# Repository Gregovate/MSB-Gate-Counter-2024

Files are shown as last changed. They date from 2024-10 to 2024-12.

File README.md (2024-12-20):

# Gate Counter Project

## Overview
The Gate Counter project is designed to monitor vehicle traffic exiting a park using sensors and microcontroller technology. It uses an ESP32 microcontroller to:

- Detect vehicles using a magnetic sensor and beam sensor.
- Log and publish vehicle counts via MQTT.
- Save data to an SD card for persistence and analysis.
- Provide real-time statistics via an OLED display.
- Enable remote monitoring and updates using WiFi and Over-The-Air (OTA) updates.

This system is an essential tool for traffic control and capacity management in parks or similar facilities.

## Features

### Sensors and Detection
- **Magnetic Sensor**: Detects metallic objects.
- **Beam Sensor**: Confirms vehicle presence.
- **Car Detection Logic**: Uses a state machine for accurate detection.

### Data Management
- Saves hourly, daily, and show-specific vehicle counts to an SD card.
- Provides recovery and persistence across reboots.
- Publishes data via MQTT to a remote server.

### Networking
- Supports multiple WiFi networks using WiFiMulti.
- Publishes car counts, temperature, humidity, and other metrics via MQTT.
- Includes a web server for file operations and remote interactions.

### Real-Time Display
- OLED display provides live updates on vehicle counts, temperature, and other metrics.

### Environmental Monitoring
- Logs temperature and humidity data using a DHT22 sensor.

### Timekeeping
- Synchronizes time using an RTC and NTP server.
- Automates actions such as resetting counts and saving summaries at specific times.

### OTA Updates
- ElegantOTA integration allows for seamless firmware updates.

---

## Documentation

For more detailed information about specific components, see the following:

- [MQTT Reset Topics](docs/mqtt_reset_topics.md): Detailed descriptions of MQTT reset topics and their payloads.
- [Changelog](docs/changelog.md): A history of updates, fixes, and new features in the Gate Counter project.

---

## Setup Instructions
1. **Hardware Requirements**:
   - ESP32 microcontroller (DOIT DevKit V1 recommended).
   - DHT22 sensor for temperature and humidity.
   - Magnetic and beam sensors for vehicle detection.
   - OLED display (128x64 resolution).
   - SD card and reader module.

2. **Software Requirements**:
   - Arduino IDE with necessary libraries:
     - `ArduinoJson`
     - `PubSubClient`
     - `Adafruit_GFX` and `Adafruit_SSD1306`
     - `RTClib`, `NTPClient`
     - `DHT` and `DHT_U`

3. **Connections**:
   - Connect sensors, SD card, and OLED display to the ESP32 as specified in the code comments.

4. **Configuration**:
   - Edit `secrets.h` to include WiFi credentials.
   - Adjust MQTT topics and server settings as needed.

5. **Deployment**:
   - Upload the firmware using Arduino IDE.
   - Monitor system logs via Serial Monitor for debugging.

---

## Future Enhancements
- Integrate a web-based dashboard for real-time monitoring.
- Add support for additional sensors and analytics.
- Improve power efficiency for extended deployments.

---

For further assistance or to contribute to the project, please contact the developer:
**Greg Liebig**  
Email: `gliebig@sheboyganlights.org`

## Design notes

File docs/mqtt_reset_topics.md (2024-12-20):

# MQTT Reset Topics - Gate Counter

This document provides descriptions for the MQTT reset topics supported by the Gate Counter system. These topics allow remote control and configuration of various counters and states within the system.

---

## Subscribed Topics for Resets

### 1. `msb/traffic/GateCounter/resetDailyCount`
- **Description**: Resets the total daily vehicle count to a specified value.
- **Payload**: Integer representing the new value for the daily counter.
- **Example**:
  - Payload: `0` (Resets the daily vehicle count to 0.)

---

### 2. `msb/traffic/GateCounter/resetShowCount`
- **Description**: Resets the total show vehicle count.
- **Payload**: Integer representing the new value for the show counter.
- **Example**:
  - Payload: `50` (Sets the show vehicle count to 50.)

---

### 3. `msb/traffic/GateCounter/resetDayOfMonth`
- **Description**: Manually resets the calendar day to a specific value.
- **Payload**: Integer representing the new day of the month.
- **Example**:
  - Payload: `15` (Sets the day of the month to the 15th.)

---

### 4. `msb/traffic/GateCounter/resetDaysRunning`
- **Description**: Resets the total number of days the show has been running.
- **Payload**: Integer representing the new value for days running.
- **Example**:
  - Payload: `10` (Resets the "days running" counter to 10.)

---

### 5. `msb/traffic/GateCounter/gateCounterTimeout`
- **Description**: Updates the timeout duration for the gate counter.
- **Payload**: Integer in milliseconds specifying the new timeout.
- **Example**:
  - Payload: `60000` (Sets the timeout duration to 60 seconds.)

---

### 6. `msb/traffic/GateCounter/carDetectMS`
- **Description**: Updates the minimum wait duration for confirming a vehicle.
- **Payload**: Integer in milliseconds specifying the new detection duration.
- **Example**:
  - Payload: `1500` (Sets the detection duration to 1.5 seconds.)

---

### 7. `msb/traffic/GateCounter/loggingEnabled`
- **Description**: Toggles the logging of sensor data.
- **Payload**:
  - `1`: Enables logging.
  - `0`: Disables logging.
- **Example**:
  - Payload: `1` (Enables logging of sensor data.)

---

## Notes
- Ensure all payloads are sent as valid integers where applicable.
- Use these topics to remotely manage the Gate Counter system for improved flexibility and responsiveness.

---

For further assistance, contact the system administrator or refer to the Gate Counter documentation.

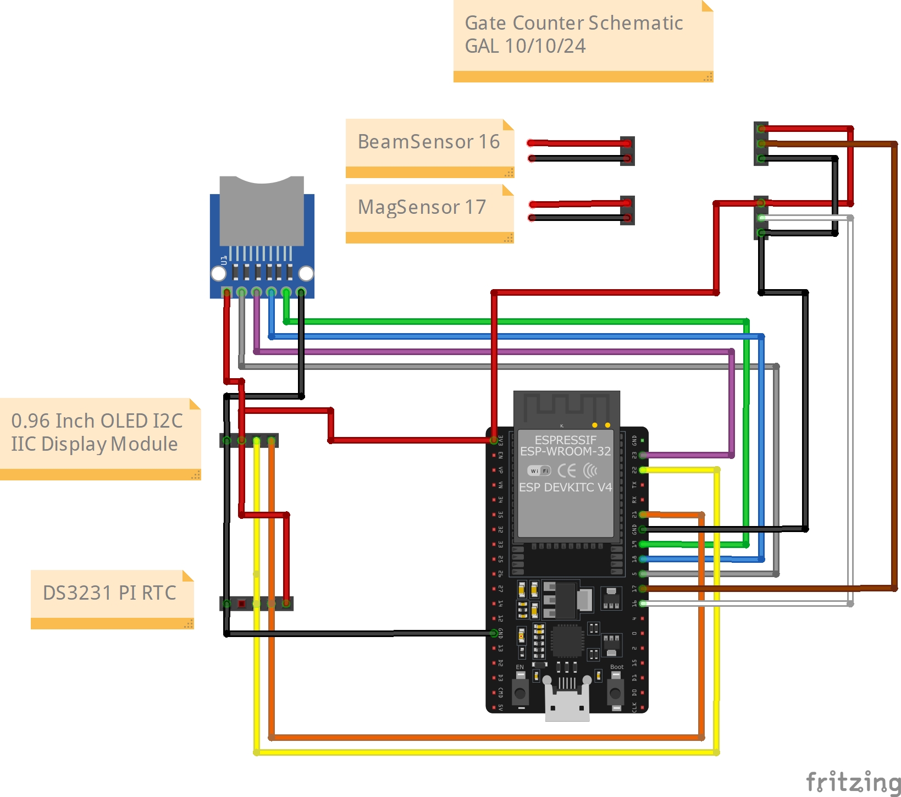
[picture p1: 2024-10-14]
docs/Gate Counter_bb.jpg

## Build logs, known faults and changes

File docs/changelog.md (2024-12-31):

### [24.12.26.1] - YYYY-MM-DD
- Added alarm if beam sensor remains high for more than 3 minutes

### [24.12.19.6] - YYYY-MM-DD
- Removed temperature array from average procedure an used the global declared array

### [24.12.19.5] - YYYY-MM-DD
- Accidentally removed mqtt_client.setCallback(callback) Fixed with a forward declaration

### [24.12.19.4] - YYYY-MM-DD
- Added save saveHourlyCounts() to countTheCar() and removed save from OTA update

### [24.12.18.4] - YYYY-MM-DD
- added  pinMode(DHTPIN, INPUT_PULLUP) for DHT Sensor getting bad readings.  77.1% (used 1010645 bytes from 1310720 bytes)

### [24.12.18.2] - YYYY-MM-DD
- put publishing state changes beamSensorState and magSensorState and timeToPassMS. detectCar() finally working reliably!

### [24.12.18.1] - YYYY-MM-DD
- Renamed hourlyCarCount[] to hourlyCount[] and finished comparison to Car Counter Code

### [24.12.17.4] - YYYY-MM-DD
- added new topic MQTT_COUNTER_LOG "msb/traffic/GateCounter/CounterLog"

### [24.12.17.3] - YYYY-MM-DD
- more tweaks to detectCar() revised averageHourlyTemp() & readTempandRH() removed averageHourlyTemp() from Loop

### [24.12.17.2] - YYYY-MM-DD
- modified detectCar() based on logging data increased predetect mag sensor to 750ms

### [24.12.17.1] - YYYY-MM-DD
- modified downloadSDFile(AsyncWebServerRequest *request) to save file with correct filename

### [24.12.16.4] - YYYY-MM-DD
- Reset counts was incorrect due to syncing code from car counter to gate counter should be 5:10 pm for gate counter

### [24.12.16.3] - YYYY-MM-DD
- was not incrementing hourly car counts and writing multiple rows for the same date

### [24.12.16.2] - YYYY-MM-DD
- removed all references to tempF from RTC sensor moved to DHT22 sensor publish every 10 min publish temp & RH json format

### [24.12.16.1] - YYYY-MM-DD
- revised saveDailyShowSummary() times to 9:20 for gate counter

### [24.12.15.4] - YYYY-MM-DD
- revised saveDailyShowSummary() to average temps during show

### [24.12.15.3] - YYYY-MM-DD
- after debugging in field after 15.2

### [24.12.15.2] - YYYY-MM-DD
- Matched Car Counter procedures, Changed Names, Added webserver

### [24.12.14.2] - YYYY-MM-DD
- added getdayofmonth() after updatingdayofmonth()

### [24.12.14.1] - YYYY-MM-DD
- Added DHT22 sensor to gate counter. Revised carDetect to weight beamSensor higher and used magSensor for additional Confirmation

### [24.12.12.3] - YYYY-MM-DD
- Tweaks to state machine for improving accuracy. Added timers for analysis topics 16 & 18

### [24.12.12.2] - YYYY-MM-DD
- Revising detectCars() State machine logic for new sensor

### [24.12.12.1] - YYYY-MM-DD
- BREAKING CHANGE Replaced reflective sensor with through beam nomally closed invert reading

### [24.12.02.3] - YYYY-MM-DD
- added timer for timeDiff between magSensor HIGH and beamSensor HIGH and timer between cars

### [24.12.02.1] - YYYY-MM-DD
- revised state machine again for through-beam sensor and removed bounce detection for beam

### [24.12.01.3] - YYYY-MM-DD
- revised state machine again for beam sensor bouncing during car detection

### [24.12.01.2] - YYYY-MM-DD
- revised state machine for beam sensor bouncing

### [24.12.01.1] - YYYY-MM-DD
- converted car dection to state machine in separate branch

### [24.11.30.3] - YYYY-MM-DD
- Totally Reworked Car Detection

### [24.11.30.2] - YYYY-MM-DD
- Refactored publishMQTT and File Checking and Creation and for loop hour counts

### [24.11.30.1] - YYYY-MM-DD
- Updated MQTT callback section to clean up potential memory leak

### [24.11.27.1] - YYYY-MM-DD
- Changed mqtt publish outside File writes, changed daily totals to string pointer, tempF to float

### [24.11.26.1] - YYYY-MM-DD
- Changed Update to days running since they were doubling on date change

### [24.11.25.2] - YYYY-MM-DD
- Added in state change in loop to publish mag sensor states. Missed 5 cars during dog show.

### [24.11.25.1] - YYYY-MM-DD
- Added MQTT Topics for Remote Reset to match Car Counter. Added Alarm for blocked beam sensor

### [24.11.19.1] - YYYY-MM-DD
- Replace Current Day & Calday with DayOfMonth. Added boolean to print daily summary once

### [24.11.18.1] - YYYY-MM-DD
- Added publishing totals on manual reset

### [24.11.15.1] - YYYY-MM-DD
- Removed Sensor Bounces, updated MQTT Topics

### [24.11.14.1] - YYYY-MM-DD
- Eliminated mqtt timeout, debug topic, added TTP to mqtt

### [24.11.10.2] - YYYY-MM-DD
- Miscellaneous formatting issues before re-creating JSON branch again

### [24.11.10.1] - YYYY-MM-DD
- Fixed bounce check, changed filename methods merged Arduino json branch

### [24.10.28.1] - YYYY-MM-DD
- Created proceedure for Updating Car Counts

### [24.10.27.1] - YYYY-MM-DD
- simplified car detect logic, Formatting Changes

### [24.10.23.3] - YYYY-MM-DD
- Fixed File creation errors

### [24.10.23.2] - YYYY-MM-DD
- Added update/reset check in loop for date changes. Created initSDCard().

### [24.10.23.1] - YYYY-MM-DD
- Updated totals, bug fixes, files ops comparrison to Gate counter  added file ops

### [24.10.17.2] - YYYY-MM-DD
- added #define FWVersion

### [24.10.15.0] - YYYY-MM-DD
- Fixed Pin problem. Beam & mag sensor swapped causing the problems. Purpose: suppliments Car Counter to improve traffic control and determine park capacity

### [23.12.13.0] - YYYY-MM-DD
- Changed time format YYYY-MM-DD hh:mm:ss 12/13/23

# Changelog

## Version History

### Version 24.12.19.3
- Synced shared code between Gate Counter and Car Counter.
- Resolved warnings and removed unused variables.
- Updated `carDetectMS` default value to 1200ms.
- Enhanced SD card file operations for better persistence.
- Fixed remaining issues with HTML file handling.

### Version 24.12.19.2
- Addressed warnings during compilation.
- Improved handling of unused variables.
- Simplified configuration settings.

### Version 24.12.19.1
- Added functionality to save hourly data before firmware updates.
- Set hostname dynamically for multiple instances.
- Improved MQTT topic structure for consistency.
- Enhanced firmware update compatibility by modifying `secrets.h`.

### Version 24.12.18.6
- Introduced `flagHourlyReset` for better hourly data saving.
- Enhanced logging capabilities for analysis and debugging.

### Version 24.12.18.5
- Added dynamic MQTT topics for hourly car totals.
- Enhanced reliability of `detectCar()` functionality.

### Version 24.12.18.3
- Added new statistics for "Time Between Cars" and beam sensor high time.
- Refined state machine logic for car detection.

### Version 24.12.16.5
- Introduced logging functions for sensor data analysis.
- Updated daily reset logic for improved consistency.

### Version 24.11.25.3
- Improved MQTT topic management.
- Resolved car detection discrepancies during specific scenarios.

### Version 24.10.24.1
- Addressed errors in MQTT variable declarations.
- Refined daily total management for better accuracy.

---

## Notes
- For further details, refer to the documentation or contact the system administrator.
- Future releases will focus on enhancing real-time analytics and integrating additional sensor support.

---

For more information, see the [README.md](README.md) file.

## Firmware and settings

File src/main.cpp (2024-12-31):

/*
Gate Counter by Greg Liebig greg@engrinnovations.com
Initial Build 12/5/2023 12:15 pm
Counts vehicles as they exit the park
Connects to WiFi and updates RTC on Boot
Uses an Optocoupler to read burried vehicle sensor for Ghost Controls Gate operating at 12V
Purpose: suppliments Car Counter to improve traffic control and determine park capacity
Uses an Optocoupler to read burried vehicle sensor for Ghost Controls Gate operating at 12V
DOIT DevKit V1 ESP32 with built-in WiFi & Bluetooth
*/

/*
## BEGIN CHANGELOG ##
24.12.26.1 Added alarm if beam sensor remains high for more than 3 minutes
24.12.19.6 Removed temperature array from average procedure an used the global declared array
24.12.19.5 Accidentally removed mqtt_client.setCallback(callback) Fixed with a forward declaration
24.12.19.4 Added save saveHourlyCounts() to countTheCar() and removed save from OTA update
24.12.19.3 File comparrison between Car Counter and Gate Counter. Synced shared code
24.12.19.2 fixed warnings, removed unused variables, Changed waitduration to carDetectMS Only errors are with html. Changed carDetectMS default 1200
24.12.19.1 Included saving hourly data before uploading new firmware, Set hostname, MultiMQTT, modified secrets.h
24.12.18.6 Changed flags to save certain data hourly flagHourlyReset
24.12.18.5 Fixed MQTT dymanic topic in CountTheCar for hourly totals 
24.12.18.4 added  pinMode(DHTPIN, INPUT_PULLUP) for DHT Sensor getting bad readings.  77.1% (used 1010645 bytes from 1310720 bytes)
24.12.18.3 Added new stat Time Between Cars. Put back BeamSensor High Time
24.12.18.2 put publishing state changes beamSensorState and magSensorState and timeToPassMS. detectCar() finally working reliably!
24.12.18.1 Renamed hourlyCarCount[] to hourlyCount[] and finished comparison to Car Counter Code
24.12.17.4 added new topic MQTT_COUNTER_LOG "msb/traffic/GateCounter/CounterLog"
24.12.17.3 more tweaks to detectCar() revised averageHourlyTemp() & readTempandRH() removed averageHourlyTemp() from Loop
24.12.17.2 modified detectCar() based on logging data increased predetect mag sensor to 750ms
24.12.17.1 modified downloadSDFile(AsyncWebServerRequest *request) to save file with correct filename
24.12.16.5 Added logging function to plot sensor data. Changes getHourlyData() & saveHoulyCounts()
24.12.16.4 Reset counts was incorrect due to syncing code from car counter to gate counter should be 5:10 pm for gate counter
24.12.16.3 was not incrementing hourly car counts and writing multiple rows for the same date
24.12.16.2 removed all references to tempF from RTC sensor moved to DHT22 sensor publish every 10 min publish temp & RH json format
24.12.16.1 revised saveDailyShowSummary() times to 9:20 for gate counter
24.12.15.4 revised saveDailyShowSummary() to average temps during show
24.12.15.3 after debugging in field after 15.2
24.12.15.2 Matched Car Counter procedures, Changed Names, Added webserver
24.12.14.2 added getdayofmonth() after updatingdayofmonth()
24.12.14.1 Added DHT22 sensor to gate counter. Revised carDetect to weight beamSensor higher and used magSensor for additional Confirmation
24.12.12.3 Tweaks to state machine for improving accuracy. Added timers for analysis topics 16 & 18
24.12.12.2 Revising detectCars() State machine logic for new sensor
24.12.12.1 BREAKING CHANGE Replaced reflective sensor with through beam nomally closed invert reading
24.12.02.3 added timer for timeDiff between magSensor HIGH and beamSensor HIGH and timer between cars
24.12.02.1 revised state machine again for through-beam sensor and removed bounce detection for beam
24.12.01.3 revised state machine again for beam sensor bouncing during car detection
24.12.01.2 revised state machine for beam sensor bouncing
24.12.01.1 converted car dection to state machine in separate branch
24.11.30.3 Totally Reworked Car Detection
24.11.30.2 Refactored publishMQTT and File Checking and Creation and for loop hour counts
24.11.30.1 Updated MQTT callback section to clean up potential memory leak
24.11.27.1 Changed mqtt publish outside File writes, changed daily totals to string pointer, tempF to float
24.11.26.1 Changed Update to days running since they were doubling on date change
24.11.25.3 Cleaned up MQTT Topics
24.11.25.2 Added in state change in loop to publish mag sensor states. Missed 5 cars during dog show.
24.11.25.1 Added MQTT Topics for Remote Reset to match Car Counter. Added Alarm for blocked beam sensor
24.11.19.1 Replace Current Day & Calday with DayOfMonth. Added boolean to print daily summary once
24.11.18.1 Added publishing totals on manual reset
24.11.15.1 Removed Sensor Bounces, updated MQTT Topics
24.11.14.1 Eliminated mqtt timeout, debug topic, added TTP to mqtt
24.11.10.2 Miscellaneous formatting issues before re-creating JSON branch again
24.11.10.1 Fixed bounce check, changed filename methods merged Arduino json branch
24.11.9.2 Added mqtt publish when car counter cars updates
24.11.9.1 Added mqtt loop to while loop. Working code excluding elegantota update
24.11.8.1 testing beamSensorBoune time
24.11.6.2 Increased carDetectTime from 500 to 750 millis Sensor bounces with my truck
24.11.6.1 Changed MQTT Topics for GateCounter rather than exit
24.11.5.1 Fixed wrong publishing topic for carCounter Counts
24.11.4.1 Removed Bounce Logic for Beam Sensor and associated vatiables added logic for show totals
24.10.28.1 Created proceedure for Updating Car Counts
24.10.27.1 simplified car detect logic, Formatting Changes
24.10.24.1 Fixed Errors in MQTT variables
24.10.23.3 Fixed File creation errors
24.10.23.2 Added update/reset check in loop for date changes. Created initSDCard(). 
24.10.23.1 Updated totals, bug fixes, files ops comparrison to Gate counter  added file ops
24.10.17.2 added #define FWVersion
24.10.15.0 Fixed Pin problem. Beam & mag sensor swapped causing the problems. Purpose: suppliments Car Counter to improve traffic control and determine park capacity
23.12.13.0 Changed time format YYYY-MM-DD hh:mm:ss 12/13/23
## END CHANGELOG ## 
*/

#include <Arduino.h>
#include <Wire.h>
#include <ArduinoJson.h>
#include <PubSubClient.h>
#include <Adafruit_GFX.h>
#include <Adafruit_SSD1306.h>
#include "RTClib.h"
#include "NTPClient.h"
//#include <WiFiClientSecure.h>
#include <WiFiMulti.h>
#include "secrets.h"
#include "time.h"
#include "SD.h"
#include "FS.h"
#include "SPI.h"
#if defined(ESP8266)
  #include <ESP8266WiFi.h>
  #include <ESPAsyncTCP.h>
#elif defined(ESP32)
  #include <WiFi.h>
  #include <AsyncTCP.h>
#endif
#include <ESPmDNS.h>
#include <ESPAsyncWebServer.h>
#include <ElegantOTAPro.h>
#include <Adafruit_Sensor.h>
#include <DHT.h>
#include <DHT_U.h>
#include <queue>  // Include queue for storing messages

// ******************** CONSTANTS *******************
#define FWVersion "24.12.26.1"   // Firmware Version
#define OTA_Title "Gate Counter" // OTA Title
#define magSensorPin 32 // Pin for Magnotometer Sensor
#define beamSensorPin 33  //Pin for Reflective Beam Sensor
#define DHTPIN 4       // GPIO pin for the DHT22
#define DHTTYPE DHT22  // DHT TYPE
#define PIN_SPI_CS 5   // The ESP32 pin GPIO5
#define OLED_RESET -1  // Reset pin # (or -1 if sharing Arduino reset pin)
#define SCREEN_ADDRESS 0x3C ///< See datasheet for Address; 0x3D for 128x64, 0x3C for 128x32
#define SCREEN_WIDTH 128 // OLED display width, in pixels
#define SCREEN_HEIGHT 64 // OLED display height, in pixels
// #define MQTT_KEEPALIVE 30 //removed 10/16/24

const int showStartMin = 17 * 60 + 10; // 5:10 PM in minutes
const int showEndMin = 21 * 60 + 20;   // 9:20 PM in minutes (including additional checks till 9:20 PM)
// **************************************************

/***** MQTT TOPIC DEFINITIONS *****/
#define THIS_MQTT_CLIENT "espGateCounter" // Look at line 90 and set variable for WiFi Client secure & PubSubCLient 12/23/23
int mqttKeepAlive = 30; // publish temp every x seconds to keep MQTT client connected
// Publishing Topics 
char topic[60];
char topicBase[60];
#define topic_base_path "msb/traffic/GateCounter"
#define MQTT_PUB_HELLO "msb/traffic/GateCounter/hello"
#define MQTT_PUB_TEMP "msb/traffic/GateCounter/temp"
#define MQTT_PUB_TIME "msb/traffic/GateCounter/time"
#define MQTT_PUB_EXIT_CARS "msb/traffic/GateCounter/ExitTotal"
#define MQTT_PUB_CARS_HOURLY  "msb/traffic/GateCounter/Cars"
#define MQTT_PUB_INPARK_CARS "msb/traffic/GateCounter/inParkCars"
#define MQTT_PUB_SUMMARY "msb/traffic/GateCounter/Summary"
#define MQTT_PUB_DAYOFMONTH "msb/traffic/GateCounter/DayOfMonth"
#define MQTT_PUB_SHOWTOTAL "msb/traffic/GateCounter/ShowTotal"
#define MQTT_PUB_TTP "msb/traffic/GateCounter/TTP"
#define MQTT_PUB_BEAM_SENSOR_STATE "msb/traffic/GateCounter/beamSensorState"
#define MQTT_PUB_MAG_SENSOR_STATE "msb/traffic/GateCounter/magSensorState"
#define MQTT_PUB_DAYSRUNNING "msb/traffic/GateCounter/DaysRunning"
#define MQTT_DEBUG_LOG "msb/traffic/GateCounter/debuglog"
#define MQTT_COUNTER_LOG "msb/traffic/GateCounter/CounterLog"
#define MQTT_PUB_MAGBEAM_MS "msb/traffic/GateCounter/mag-beam_ms"
#define MQTT_PUB_BETWEENCARS_MS "msb/traffic/GateCounter/betweenCars"
#define MQTT_PUB_BEAMHIGH_MS "msb/traffic/GateCounter/beam-high_ms"
// Subscribing Topics (to reset values)
#define MQTT_SUB_TOPIC0  "msb/traffic/CarCounter/EnterTotal"          // get enter counts from carCounter
#define MQTT_SUB_TOPIC1  "msb/traffic/GateCounter/resetDailyCount"    // Reset Daily counter
#define MQTT_SUB_TOPIC2  "msb/traffic/GateCounter/resetShowCount"     // Resets Show Counter
#define MQTT_SUB_TOPIC3  "msb/traffic/GateCounter/resetDayOfMonth"    // Reset Calendar Day
#define MQTT_SUB_TOPIC4  "msb/traffic/GateCounter/resetDaysRunning"   // Reset Days Running
#define MQTT_SUB_TOPIC5  "msb/traffic/GateCounter/gateCounterTimeout" // Reset Timeout if car leaves detection Zone
#define MQTT_SUB_CARMS  "msb/traffic/GateCounter/carDetectMS"       // Reset sync time from magSensor trip to beamSensor Active
#define MQTT_SUB_LOGGING "msb/traffic/GateCounter/loggingEnabled"     // toggle logging function

// State Machine for Car Counting
enum CarDetectionState {
    IDLE,
    MAG_SENSOR_TRIGGERED,
    BEAM_SENSOR_VALIDATION,
    VEHICLE_CONFIRMED
};
CarDetectionState carDetectionState = IDLE;

unsigned long magSensorTripTime = 0;     // Time when the magnetometer was first triggered
unsigned long beamSensorTripTime = 0;    // Time when the beam sensor was first triggered
unsigned long lastCarExitTime = 0;       // Time when the last car exited (beam sensor went low)
static int carDetectMS = 1200;           // Minimum wait duration for a vehicle to be confirmed
unsigned long timeToPassMS = 0;          // Time from start of detection to confirmation
bool magSensorWasTriggered = false;      // Tracks if the magnetic sensor was triggered recently
bool carPassed = false;                  // Tracks if a car has fully passed through

// Track previous states for efficient MQTT publishing
int prevMagSensorState = -1;  // Start with -1 to ensure initial publishing
int prevBeamSensorState = -1; // Start with -1 to ensure initial publishing

AsyncWebServer server(80);     // Define Webserver
String currentDirectory = "/"; // Current working directory

unsigned long ota_progress_millis = 0;

//void saveHourlyCounts();  // forward declaration

void onOTAStart() {
  // Log when OTA has started
  Serial.println("OTA update started!");
  //saveHourlyCounts();
}

void onOTAProgress(size_t current, size_t final) {
  // Log every 1 second
  if (millis() - ota_progress_millis > 1000) {
    ota_progress_millis = millis();
    Serial.printf("OTA Progress Current: %u bytes, Final: %u bytes\n", current, final);
  }
}

void onOTAEnd(bool success) {
    // Log when OTA has finished
    if (success) {
      Serial.println("OTA update finished successfully!");
    } else {
      Serial.println("There was an error during OTA update!");
    }
    // <Add your own code here>
}

/** REAL TIME Clock & Time Related Variables **/
RTC_DS3231 rtc;
const char* ampm ="AM";
const char* ntpServer = "pool.ntp.org";
const long  gmtOffset_sec = -21600;
const int   daylightOffset_sec = 3600;
//float tempF = 0.0;

// Initialize DHT sensor & Variables for temperature and humidity readTempandRH()
DHT dht(DHTPIN, DHTTYPE);
float tempF = 0.0;  // Temperature
float humidity = 0.0;     // Humidity

/** Display Definitions & variables **/
Adafruit_SSD1306 display(SCREEN_WIDTH, SCREEN_HEIGHT, &Wire, OLED_RESET);
/*Line Numbers used for Display*/
const int line1 =0;
const int line2 =9;
const int line3 = 19;
const int line4 = 30;
const int line5 = 42;
const int line6 = 50;
const int line7 = 53;

//Create Multiple WIFI Object
WiFiMulti wifiMulti;
//WiFiClientSecure espGateCounter;
WiFiClient espGateCounter;

//const uint32_t connectTimeoutMs = 10000;
uint16_t connectTimeOutPerAP=5000;

/***** MQTT Setup Variables  *****/
PubSubClient mqtt_client(espGateCounter);
unsigned long lastMsg = 0;
#define MSG_BUFFER_SIZE (500)
char msg[MSG_BUFFER_SIZE];
//char mqtt_server[] = mqtt_Server;
//char mqtt_username[] = mqtt_UserName;
//char mqtt_password[] = mqtt_Password;
//const int mqtt_port = mqtt_Port;
bool loggingEnabled = false; // Default: Logging is OFF
bool mqtt_connected = false;
bool wifi_connected = false;
int wifi_connect_attempts = 5;
bool hasRun = false;

/***** GLOBAL VARIABLES *****/
unsigned int dayOfMonth;      // Current Calendar day
unsigned int lastDayOfMonth;  // Last calendar day used to reset days running
unsigned int currentHr12;     // Current Hour 12 Hour format
unsigned int currentHr24;     // Current Hour 24 Hour Format
unsigned int currentMin;      // Current Minute
unsigned int currentSec;      // Current Second
unsigned int daysRunning;     // Number of days the show is running.
unsigned int currentTimeMinute; // for converting clock time hh:mm to clock time min since midnight
int totalDailyCars; // total cars counted per day 24/7 Needed for debugging
int totalShowCars;  // total cars counted for durning show hours open (5:00 pm to 9:10 pm)
int inParkCars;     // cars in park Enter Cars - Exit Cars
int carCounterCars; // Counts from Car Counter
int lastcarCounterCars; // Used to publish in park cars when car counter increases
int magSensorState, lastmagSensorState ; /* Store states of Mag Sensor*/
int beamSensorState, lastbeamSensorState ; /* Store states of Beam Sensor */
unsigned long triggerTime; // Stores the time when sensor 1 is triggered
unsigned long beamSensorAlarm; // Monitor time Beam Sensor is blocked


/***** TIME VARIABLES *****/
const unsigned long wifi_connectioncheckMillis = 5000; // check for connection every 5 sec
const unsigned long mqtt_connectionCheckMillis = 30000; // check for connection
unsigned long start_MqttMillis; // for Keep Alive Timer
unsigned long start_WiFiMillis; // for keep Alive Timer
int gateCounterTimeout = 60000; // default time for car counter alarm in millis
char buf2[25] = "YYYY-MM-DD hh:mm:ss"; // time car detected

//***** DAILY RESET FLAGS *****
bool flagDaysRunningReset = false;
bool flagMidnightReset = false;
bool flagDailyShowStartReset = false;
bool flagDailySummarySaved = false;
bool flagDailyShowSummarySaved = false;
bool flagHourlyReset = false;
bool showTime = false;
bool resetFlagsOnce = false;

// **********FILE NAMES FOR SD CARD *********
File myFile; //used to write files to SD Card
const String fileName1 = "/ExitTotal.txt"; // /DailyTot.txt file to store daily counts in the event of a Failure
const String fileName2 = "/ShowTotal.txt";  // /ShowTot.txt file to store season total counts
const String fileName3 = "/DayOfMonth.txt"; // /DayOfMonth.txt file to store current day number
const String fileName4 = "/RunDays.txt"; // /RunDays.txt file to store days since open
const String fileName5 = "/GateHourlyData.csv"; // /GateSummary.csv Stores Daily Totals by Hour and total
const String fileName6 = "/GateLog.csv"; // GateLog.csv file to store all car counts for season (was MASTER.CSV)
const String fileName7 = "/GateDailySummary.csv"; // Show summary of counts during show (5:00pm to 9:10pm)
const String fileName8 = "/data/index.html"; // data folder and index.html for serving files OTA
const String fileName9 = "/data/style.css"; // data folder and index.html for serving files OTA
const String fileName10 = "/SensorLog.csv"; // sensorLog.csv for recording gate sensors for plotting
//const String fileName7 = "/SensorBounces.csv"; // /SensorBounces.csv file to store all bounce counts for season

/***** Arrays for Hourly Totals/Averages *****/
static unsigned int hourlyCount[24] = {0}; // Array for Daily total cars per hour
static float hourlyTemp[24] = {0.0};   // Array to store average temperatures for 24 hours

/***** Arrays Used to make display Pretty *****/
static char days[7][4] = {"Sun", "Mon", "Tue", "Wed", "Thu", "Fri", "Sat"};
static char months[12][4] = {"Jan", "Feb", "Mar", "Apr", "May", "Jun", "Jul", "Aug", "Sep", "Oct", "Nov", "Dec"};

// sync Time at REBOOT
void SetLocalTime()  {
  struct tm timeinfo;
  if(!getLocalTime(&timeinfo)) {
    Serial.println("Failed to obtain time. Using Compiled Date");
    return;
  }
  //Following used for Debugging and can be commented out
  Serial.println(&timeinfo, "%A, %B %d %Y %H:%M:%S");
  Serial.print("Day of week: ");
  Serial.println(&timeinfo, "%A");
  Serial.print("Month: ");
  Serial.println(&timeinfo, "%B");
  Serial.print("Day of Month: ");
  Serial.println(&timeinfo, "%d");
  Serial.print("Year: ");
  Serial.println(&timeinfo, "%Y");
  Serial.print("Hour: ");
  Serial.println(&timeinfo, "%H");
  Serial.print("Hour (12 hour format): ");
  Serial.println(&timeinfo, "%I");
  Serial.print("Minute: ");
  Serial.println(&timeinfo, "%M");
  Serial.print("Second: ");
  Serial.println(&timeinfo, "%S");
  Serial.println("Time variables");
  char timeHour[3];
  strftime(timeHour,3, "%H", &timeinfo);
  Serial.println(timeHour);
  char timeWeekDay[10];
  strftime(timeWeekDay,10, "%A", &timeinfo);
  Serial.println(timeWeekDay);
  Serial.println();

  // Convert NTP time string to set RTC
  char timeStringBuff[50]; //50 chars should be enough
  strftime(timeStringBuff, sizeof(timeStringBuff), "%Y-%m-%d %H:%M:%S", &timeinfo);
  Serial.println(timeStringBuff);
  rtc.adjust(DateTime(timeStringBuff));
}

void setup_wifi()  {
    Serial.println("Connecting to WiFi");
    display.println("Connecting to WiFi..");
    display.display();
    while(wifiMulti.run(connectTimeOutPerAP) != WL_CONNECTED) {
        Serial.print(".");
    }
    Serial.println("Connected to the WiFi network");
    display.clearDisplay();
    display.setTextColor(WHITE);
    display.setTextSize(1);
    display.display();
  
    display.setCursor(0, line1);
    display.print("SSID: ");
    display.println(WiFi.SSID());   // print the SSID of the network you're attached to:
    Serial.print("SSID: ");
    Serial.println(WiFi.SSID());
    
    IPAddress ip = WiFi.localIP();  // print your board's IP address:
    Serial.print("IP: ");
    Serial.println(ip);
    display.setCursor(0, line2);
    display.print("IP: ");
    display.println(ip);
    
    long rssi = WiFi.RSSI();
    Serial.print("signal strength (RSSI):");
    Serial.print(rssi);
    Serial.println(" dBm");
    display.setCursor(0, line3);
    display.print("signal: ");
    display.print(rssi);  // print the received signal strength:
    display.println(" dBm");
    display.display();
 
    delay(1000);
}  // END WiFi Setup

// BEGIN OTA SD Card File Operations
void listSDFiles(AsyncWebServerRequest *request) {
    String fileList = "Files in " + currentDirectory + ":\n";

    File root = SD.open(currentDirectory);
    if (!root || !root.isDirectory()) {
        request->send(500, "text/plain", "Failed to open directory");
        return;
    }

    File file = root.openNextFile();
    while (file) {
        fileList += String(file.name()) + " (" + String(file.size()) + " bytes)\n";
        file = root.openNextFile();
    }

    request->send(200, "text/plain", fileList);
}

void downloadSDFile(AsyncWebServerRequest *request) {
    if (!request->hasParam("filename")) {
        request->send(400, "text/plain", "Filename is required");
        return;
    }

    String filename = currentDirectory + request->getParam("filename")->value();
    if (!SD.exists(filename)) {
        request->send(404, "text/plain", "File not found");
        return;
    }

    // Add Content-Disposition header for proper filename handling
    AsyncWebServerResponse *response = request->beginResponse(SD, filename, "application/octet-stream");
    response->addHeader("Content-Disposition", "attachment; filename=\"" + String(request->getParam("filename")->value()) + "\"");

    request->send(response);
}
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
void loop() {  
    DateTime now = rtc.now();

    currentTimeMinute = now.hour()*60 + now.minute(); // convert time to minutes since midnight

    showTime = (currentTimeMinute >= showStartMin && currentTimeMinute <= showEndMin); // show is running and save counts

    readTempandRH();          // Get Temperature and Humidity

    ElegantOTA.loop();        // Keep OTA Updates Alive

    updateDisplay();          // Update the display

    checkWiFiConnection();    // Check and maintain WiFi connection

    timeTriggeredEvents();    // Various functions/saves/resets based on time of day

    detectCar();              // Detect cars

    //Added to kepp mqtt connection alive and periodically publish select values
    if ((millis() - start_MqttMillis) > (mqttKeepAlive * 1000)) {
        KeepMqttAlive();
    }
} 
/***** Repeat Loop *****/

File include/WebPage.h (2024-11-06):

/*


  OK, ya ready for some fun? HTML + CSS styling + javascript all in and undebuggable environment

  one trick I've learned to how to debug HTML and CSS code.

  get all your HTML code (from html to /html) and past it into this test site
  muck with the HTML and CSS code until it's what you want
  https://www.w3schools.com/html/tryit.asp?filename=tryhtml_intro

  No clue how to debug javascrip other that write, compile, upload, refresh, guess, repeat

  I'm using class designators to set styles and id's for data updating
  for example:
  the CSS class .tabledata defines with the cell will look like
  <td><div class="tabledata" id = "switch"></div></td>

  the XML code will update the data where id = "switch"
  java script then uses getElementById
  document.getElementById("switch").innerHTML="Switch is OFF";


  .. now you can have the class define the look AND the class update the content, but you will then need
  a class for every data field that must be updated, here's what that will look like
  <td><div class="switch"></div></td>

  the XML code will update the data where class = "switch"
  java script then uses getElementsByClassName
  document.getElementsByClassName("switch")[0].style.color=text_color;


  the main general sections of a web page are the following and used here

  <html>
    <style>
    // dump CSS style stuff in here
    </style>
    <body>
      <header>
      // put header code for cute banners here
      </header>
      <main>
      // the buld of your web page contents
      </main>
      <footer>
      // put cute footer (c) 2021 xyz inc type thing
      </footer>
    </body>
    <script>
    // you java code between these tags
    </script>
  </html>


*/

// note R"KEYWORD( html page code )KEYWORD"; 
// again I hate strings, so char is it and this method let's us write naturally

const char PAGE_MAIN[] PROGMEM = R"=====(

<!DOCTYPE html>
<html lang="en" class="js-focus-visible">

<title>Web Page Update Demo</title>

  <style>
    table {
      position: relative;
      width:100%;
      border-spacing: 0px;
    }
    tr {
      border: 1px solid white;
      font-family: "Verdana", "Arial", sans-serif;
      font-size: 20px;
    }
    th {
      height: 20px;
      padding: 3px 15px;
      background-color: #343a40;
      color: #FFFFFF !important;
      }
    td {
      height: 20px;
       padding: 3px 15px;
    }
    .tabledata {
      font-size: 24px;
      position: relative;
      padding-left: 5px;
      padding-top: 5px;
      height:   25px;
      border-radius: 5px;
      color: #FFFFFF;
      line-height: 20px;
      transition: all 200ms ease-in-out;
      background-color: #00AA00;
    }
    .fanrpmslider {
      width: 30%;
      height: 55px;
      outline: none;
      height: 25px;
    }
    .bodytext {
      font-family: "Verdana", "Arial", sans-serif;
      font-size: 24px;
      text-align: left;
      font-weight: light;
      border-radius: 5px;
      display:inline;
    }
    .navbar {
      width: 100%;
      height: 50px;
      margin: 0;
      padding: 10px 0px;
      background-color: #FFF;
      color: #000000;
      border-bottom: 5px solid #293578;
    }
    .fixed-top {
      position: fixed;
      top: 0;
      right: 0;
      left: 0;
      z-index: 1030;
    }
    .navtitle {
      float: left;
      height: 50px;
      font-family: "Verdana", "Arial", sans-serif;
      font-size: 50px;
      font-weight: bold;
      line-height: 50px;
      padding-left: 20px;
    }
   .navheading {
     position: fixed;
     left: 60%;
     height: 50px;
     font-family: "Verdana", "Arial", sans-serif;
     font-size: 20px;
     font-weight: bold;
     line-height: 20px;
     padding-right: 20px;
   }
   .navdata {
      justify-content: flex-end;
      position: fixed;
      left: 70%;
      height: 50px;
      font-family: "Verdana", "Arial", sans-serif;
      font-size: 20px;
      font-weight: bold;
      line-height: 20px;
      padding-right: 20px;
   }
    .category {
      font-family: "Verdana", "Arial", sans-serif;
      font-weight: bold;
      font-size: 32px;
      line-height: 50px;
      padding: 20px 10px 0px 10px;
      color: #000000;
    }
    .heading {
      font-family: "Verdana", "Arial", sans-serif;
      font-weight: normal;
      font-size: 28px;
      text-align: left;
    }
  
    .btn {
      background-color: #444444;
      border: none;
      color: white;
      padding: 10px 20px;
      text-align: center;
      text-decoration: none;
      display: inline-block;
      font-size: 16px;
      margin: 4px 2px;
      cursor: pointer;
    }
    .foot {
      font-family: "Verdana", "Arial", sans-serif;
      font-size: 20px;
      position: relative;
      height:   30px;
      text-align: center;   
      color: #AAAAAA;
      line-height: 20px;
    }
    .container {
      max-width: 1800px;
      margin: 0 auto;
    }
    table tr:first-child th:first-child {
      border-top-left-radius: 5px;
    }
    table tr:first-child th:last-child {
      border-top-right-radius: 5px;
    }
    table tr:last-child td:first-child {
      border-bottom-left-radius: 5px;
    }
    table tr:last-child td:last-child {
      border-bottom-right-radius: 5px;
    }
    
  </style>
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

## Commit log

2024-10-14 removing history
    [Gate Counter.fzz]
2024-10-15 Reverted to morning changes and fixed pin assignments
    [main.cpp]
2024-10-16 Cleaned up indentation, spelling corrections, compile OK
    [main.cpp]
2024-10-16 renoved keepalive and sensorbouncecount ==
2024-10-17 changed platformio.ini ota not working
    [main.cpp]
2024-10-18 Changed pin numbers for sesnors to 32 Mag & 33 Beam
2024-10-19 changed comment spi pin
2024-10-24 24.10.23.3 Fixed File creation errors
    [main.cpp]
2024-10-25 24.10.24.1 Fixed Errors in MQTT variables
    [main.cpp]
2024-11-05 24.11.4.1 Removed Bounce Logic for Beam Sensor and associated vatiables added logic for show totals
2024-11-06 24.11.6.2 Increased carDetectTime from 500 to 750 millis
2024-11-10 24.11.10.1 Fixed bounce check, changed filename methods merged Arduino json branch
    [main.cpp]
2024-11-10 24.11.10.2 Miscellaneous formatting issues before re-creating JSON branch again
    [main.cpp]
2024-11-15 24.11.15.1 Removed Sensor Bounces, updated MQTT Topics
2024-11-25 24.11.25.1 Added MQTT Topics for Remote Reset to match Car Counter. Added Alarm for blocked beam sensor
    [main.cpp]
2024-12-01 24.11.30.3 Totally Reworked Car Detection
    [main.cpp]
2024-12-03 24.12.02.1 revised state machine again for through-beam sensor and removed bounce detection for beam
2024-12-03 24.12.02.3 added timer for timeDiff between magSensor HIGH and beamSensor HIGH and timer between cars
2024-12-12 24.12.12.1 BREAKING CHANGE Replaced reflective sensor with through beam nomally closed invert readingte machine branch to main
    [main.cpp]
2024-12-13 24.12.12.2 Revising detectCars() State machine logic for new sensor
2024-12-13 24.12.12.3 Tweaks to state machine for improving accuracy. Added timers for analysis topics 16 & 18
2024-12-14 24.12.14.1 Added DHT22 sensor to gate counter. Revised carDetect to weight beamSensor higher and used magSensor for additional Confirmation
2024-12-16 24.12.16.2 removed all references to tempF from RTC sensor moved to DHT22 sensor publish every 10 min publish temp & RH json format
2024-12-17 24.12.16.5 Added logging function to plot sensor data. Changes getHourlyData() & saveHoulyCounts()
2024-12-18 24.12.17.2 modified detectCar() based on logging data increased predetect mag sensor to 750ms
2024-12-19 24.12.18.4 added pinMode(DHTPIN, INPUT_PULLUP) for DHT Sensor getting bad readings. 77.1% (used 1010645 bytes from 1310720 bytes)
2024-12-19 24.12.19.2 fixed warnings, removed unused variables, Changed waitduration to carDetectMS Only errors are with html. Changed carDetectMS default 1200
    [main.cpp]
2024-12-27 24.12.26.1 Added alarm if beam sensor remains high for more than 3 minutes
